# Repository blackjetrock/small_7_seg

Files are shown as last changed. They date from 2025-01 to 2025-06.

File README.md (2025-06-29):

# Small 7 segent LED module

This is a fifteen digit seven segment display made form a PCB with SMD LEDs on it and a 3D printed frme to form the segments. A diffuser is needed over the top of the frame to even the light over the segment.



This construction is similar to larger displays that can be bought, it's just a bit smaller and more dense in terms of the number of digits. The PCB is about 60mm wide and 14mm high. The PCB was hand assembled and then soldered in a reflow oven, but it should be possible to get it assembled by a PCB manufacturer. The LEDs are red. There's no filter. The display looks a lot better in real life than in the photos, it's very difficult to photograph this display. The diffuser is a piece of masking tape stuck over the display at the moment, this also holds the frame on to the PCB, That coud be tidied up.

The frame is 3D printed from resin. This is a white version (which doesn't work):

IMG_20250219_060615580_HDR

The white resin doesn't block light well enough, a black resin version is used on the frame attached to the prototype.

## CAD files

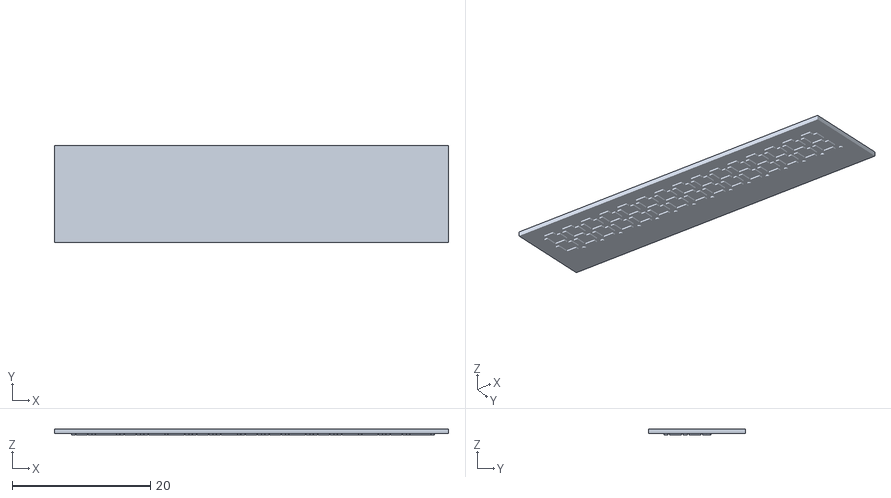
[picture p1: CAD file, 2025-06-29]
small_led_a_openscad/small_led_a_diff_0_1_0_9.stl
57.0 x 14.0 x 0.9

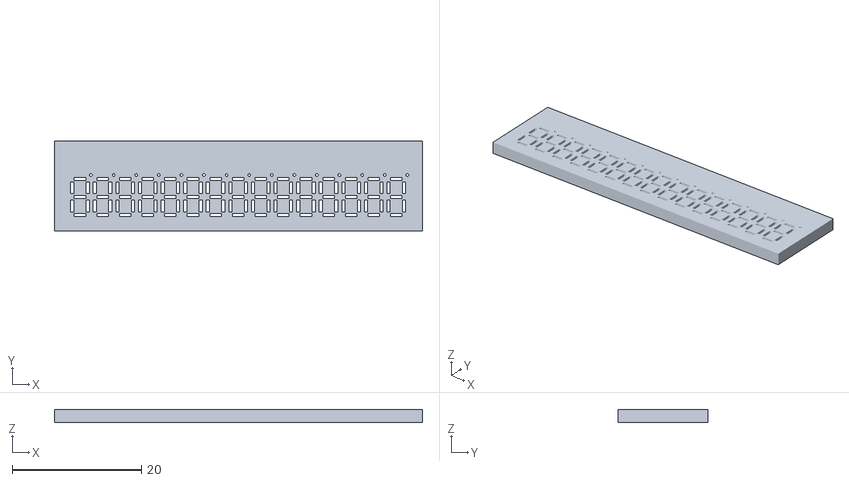
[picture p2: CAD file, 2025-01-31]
small_led_a_openscad/small_led_a.stl
57.0 x 14.0 x 2.00

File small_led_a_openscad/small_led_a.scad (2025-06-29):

module pre()
{
cube([57, 14, 2], center=true);
}

module rem()
{
    translate([-7*3.5-2.5/2, 3.9-7, 0])
    {
for(i=[0:3.5:14*3.5])
{    
translate([i, 0, 0])
{
digit();
}
}
}
}

// Clearance so diffuser fits inside mask holes.

w = 0.1;

module cut()
{
cube([0.7-w, 1.8-w, 3], center=true);
}

module rcut()
{
cube([1.8-w, 0.7-w, 3], center=true);
}

module digit()
{
    
translate([1.2, -1.4, 0])
    {
    rcut();
    }

translate([1.2, 1.4, 0])
    {
    rcut();
    }

translate([1.2, 4.2, 0])
    {
    rcut();
    }
    
cut();
translate([2.4, 0, 0])
{
    cut();
}    
translate([2.9, 4.8, 0])
{
cylinder(d=0.7-w, h = 3, $fn =30, center=true);
}

translate([0, 2.8, 0])
{
cut();
translate([2.4, 0, 0])
{
    cut();
}    
}
}

module mask()
{
    difference()
    {
        pre();
        rem();
    }
}

dh = 0.9;
dd = 0.2;

module diffuser()
{
translate([0, 0, 2/2+dh/2-dd])
    {
    cube([57, 14, dh], center=true);
    }
}

domask = 0;
dodiff = 1;

if(domask)
{
mask();
}

if(dodiff)
{
difference()
    {
        diffuser();
        mask();
    }
}

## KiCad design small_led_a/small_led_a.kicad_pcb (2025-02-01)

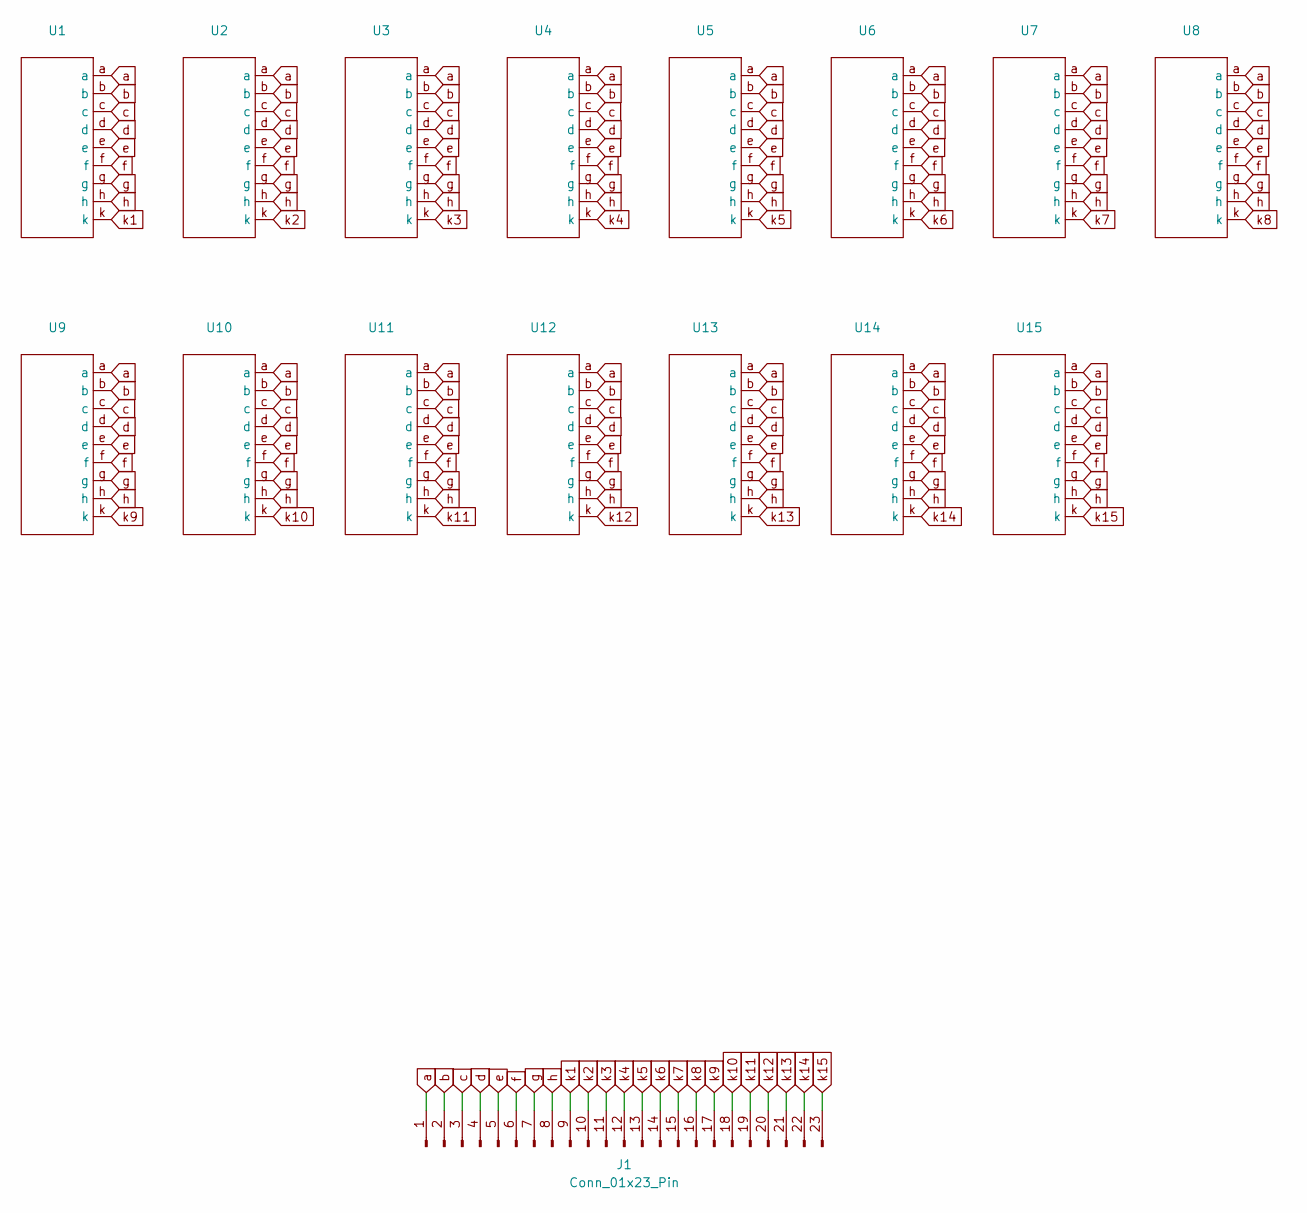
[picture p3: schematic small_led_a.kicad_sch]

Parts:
J1: Conn_01x23_Pin; PinHeader_1x23_P1.27mm_Vertical
U1, U2, U3, U4, U5, U6, U7, U8, U9, U10, U11, U12, U13, U14, U15: seg7_0402

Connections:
a: J1.1, U1.a, U2.a, U3.a, U4.a, U5.a, U6.a, U7.a, U8.a, U9.a, U10.a, U11.a, U12.a, U13.a, U14.a, U15.a
b: J1.2, U1.b, U2.b, U3.b, U4.b, U5.b, U6.b, U7.b, U8.b, U9.b, U10.b, U11.b, U12.b, U13.b, U14.b, U15.b
c: J1.3, U1.c, U2.c, U3.c, U4.c, U5.c, U6.c, U7.c, U8.c, U9.c, U10.c, U11.c, U12.c, U13.c, U14.c, U15.c
d: J1.4, U1.d, U2.d, U3.d, U4.d, U5.d, U6.d, U7.d, U8.d, U9.d, U10.d, U11.d, U12.d, U13.d, U14.d, U15.d
e: J1.5, U1.e, U2.e, U3.e, U4.e, U5.e, U6.e, U7.e, U8.e, U9.e, U10.e, U11.e, U12.e, U13.e, U14.e, U15.e
f: J1.6, U1.f, U2.f, U3.f, U4.f, U5.f, U6.f, U7.f, U8.f, U9.f, U10.f, U11.f, U12.f, U13.f, U14.f, U15.f
g: J1.7, U1.g, U2.g, U3.g, U4.g, U5.g, U6.g, U7.g, U8.g, U9.g, U10.g, U11.g, U12.g, U13.g, U14.g, U15.g
h: J1.8, U1.h, U2.h, U3.h, U4.h, U5.h, U6.h, U7.h, U8.h, U9.h, U10.h, U11.h, U12.h, U13.h, U14.h, U15.h
k1: J1.9, U1.k
k2: J1.10, U2.k
k3: J1.11, U3.k
k4: J1.12, U4.k
k5: J1.13, U5.k
k6: J1.14, U6.k
k7: J1.15, U7.k
k8: J1.16, U8.k
k9: J1.17, U9.k
k10: J1.18, U10.k
k11: J1.19, U11.k
k12: J1.20, U12.k
k13: J1.21, U13.k
k14: J1.22, U14.k
k15: J1.23, U15.k

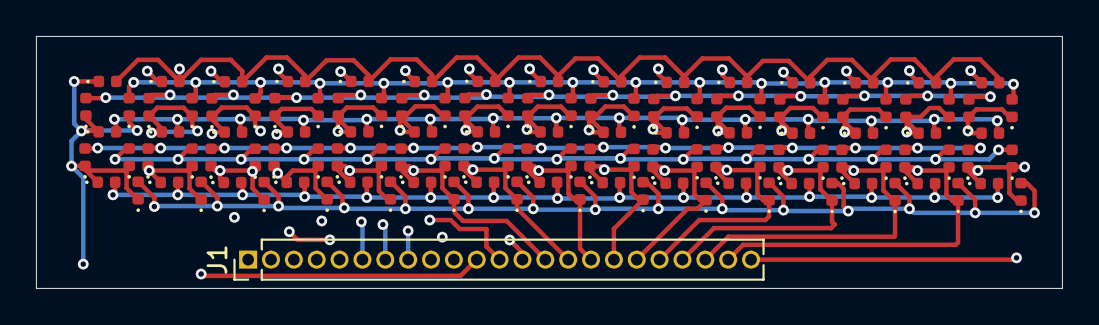
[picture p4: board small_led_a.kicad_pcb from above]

Board: 4 copper layers, 57.0 x 14.0 mm, 16 parts (0 on the bottom side), 23 nets.

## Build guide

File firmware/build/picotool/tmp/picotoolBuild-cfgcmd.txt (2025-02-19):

cmd='/usr/bin/cmake;--no-warn-unused-cli;-DCMAKE_MAKE_PROGRAM:FILEPATH=/usr/bin/gmake;-DPICO_SDK_PATH:FILEPATH=/home/menadue/pico/pico-sdk;-DPICOTOOL_NO_LIBUSB=1;-DPICOTOOL_FLAT_INSTALL=1;-DCMAKE_INSTALL_PREFIX=/home/menadue/tree/github/small_7_seg/firmware/build/_deps;-DCMAKE_RULE_MESSAGES=OFF;-DCMAKE_INSTALL_MESSAGE=NEVER;-GUnix Makefiles;-S;<SOURCE_DIR><SOURCE_SUBDIR>;-B;<BINARY_DIR>'

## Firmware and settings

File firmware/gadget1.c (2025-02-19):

////////////////////////////////////////////////////////////////////////////////
//
// Small 7 Segment Test Program
//
// Drives a test pattern to the 15 digit 7 segment display
//
////////////////////////////////////////////////////////////////////////////////

#include <stdarg.h>
#include <ctype.h>
#include <stdio.h>
#include <string.h>
#include <stdlib.h>
#include "pico/stdlib.h"
#include "hardware/pio.h"
#include "hardware/clocks.h"
#include "pico/multicore.h"
#include "pico/bootrom.h"


////////////////////////////////////////////////////////////////////////////////
//
// Main Loop
//
// Two itmes are serviced here, the menu for the OLED and the serial USB
// interface
//
////////////////////////////////////////////////////////////////////////////////

#define BLANK 11
#define H1    12
#define H2    13
#define H3    14

int pat[20][8] =
    {
      {1,1,1,1,1,1,1,1},
      {1,1,1,1,1,1,1,1},
      {1,1,1,1,1,1,1,1},
      {1,1,1,1,1,1,1,1},
      {1,1,1,1,1,1,1,1},
      {1,1,1,1,1,1,1,1},
      {1,1,1,1,1,1,1,1},
      {1,1,1,1,1,1,1,1},
      {1,1,1,1,1,1,1,1},
      {1,1,1,1,1,1,1,1},
      {1,1,1,1,1,1,1,1},   // 10
      {1,1,1,1,1,1,1,1},
      {1,1,1,1,1,1,1,1},
      {1,1,1,1,1,1,1,1},
      {1,1,1,1,1,1,1,1},
      {1,1,1,1,1,1,1,1},
    };

int ch[][8] =
  {
    {1,1,1,1,1,1,0,0},   //0
    {0,1,1,0,0,0,0,0},
    {1,1,0,1,1,0,1,0},   //2
    {1,1,1,1,0,0,1,0},
    {0,1,1,0,0,1,1,0},   //4
    {1,0,1,1,0,1,1,0},
    {1,0,1,1,1,1,1,0},   //6
    {1,1,1,0,0,0,0,0},
    {1,1,1,1,1,1,1,0},   //8
    {1,1,1,1,0,1,1,0},

    {1,1,1,1,1,1,1,0},
    {0,0,0,0,0,0,0,0},   // BLANK
    {1,0,0,0,0,0,0,0},   // H1
    {0,0,0,1,0,0,0,0},   // H2
    {0,0,0,0,0,0,1,0},   // H3
    {0,0,0,0,0,0,0,0},
  };

int c = 0;
int num = 0;

int seg[8] =
  {
    16, 17, 18, 19, 20, 21, 22, 26
  };

void copy_char(int c, int d)
{
  for(int i=0; i<8; i++)
    {
      pat[d][i] = ch[c][i];
    }
}

void blank_digits(void)
{
  for(int d=0; d<15; d++)
    {
      copy_char(BLANK, d);
    }
}

void disp_int(int s, int dp, int n)
{
  int ten = 1;
  int invd;
  int dn;
    
  for(int d=s; d<s+dp; d++)
    {
      invd = 14-d;

      dn = (n / ten) % 10;
      copy_char(dn, invd);
      ten *=10;
    }
}


int main()
{
  char line[80];

  stdio_init_all();
  sleep_us(1000);
  
  printf("\n\nSeven segment test program\n\n");
  printf("\nInitialising...");
  
  printf("\nSetting GPIOs...");
  
  // Init gpios

  for(int g=0; g<=14; g++)
    {
      gpio_init(g);
      gpio_set_dir(g, GPIO_OUT);
      gpio_put(g, 1);
    }

  for(int g=0; g<8; g++)
    {
      gpio_init(seg[g]);
      gpio_set_dir(seg[g], GPIO_OUT);
      gpio_put(seg[g], 0);
    }

  int k = 0;
  int k2 = 0;
  int k3 = 0;
  int k4 = 0;
  int k30 = 0;
  int k40 = 0;
  
  int num2 = 0;
  
  // test scan
  while(1)
    {
      k++;

      if( (k % 5) == 0 )
	{
	  c = c + 1;
	  c %= 10;

	  blank_digits();
	  disp_int(0, 10, num++);
	  disp_int(12, 3, num2);

	  k2++;
	  k3++;
	  k4++;
	  
	  if( (k2 % 100)==0 )
	    {
	      num2 *= 17;
	      num2 += 19;
	    }

	  if( (k3 % 30)==0 )
	    {
	      k30++;
	      k30 %= 3;
	    }

	  if( (k4 % 70)==0 )
	    {
	      k40++;
	      k40 %= 3;
	    }

	  copy_char(H1+k30, 14-11);
	  copy_char(H1+k40, 14-10);
	  pat[9][7] = 1;
	  
	}
      
      for(int g=0; g<=14; g++)
	{
	  for(int i=0; i<8;i++)
	    {
	      gpio_put(seg[i], pat[g][i]);
	    }
	  
	  gpio_put(g, 0);
	  sleep_us(100);
	  gpio_put(g, 1);
	}
    }
}
